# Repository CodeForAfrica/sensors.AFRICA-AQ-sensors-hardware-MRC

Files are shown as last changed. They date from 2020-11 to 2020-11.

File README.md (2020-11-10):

# sensors.AFRICA MRC AQ Kits Hardware

## Tools used

* Autodesk Eagle

* Fusion360

## sensors.AFRICA Stack

1. Firmware - https://github.com/CodeForAfrica/sensors.AFRICA-AQ-sensors-software
2. API - https://github.com/CodeForAfricaLabs/sensors.AFRICA-AQ-api
3. Map - https://github.com/CodeForAfrica/sensors.AFRICA-AQ-map-v2

## Documentation

The Documentation is under development.

## License

GNU General Public License v3.0

sensors.AFRICA is a citizen-science focused project by Code for Africa that seeks to address data gaps by providing low cost sensors, which people can use to measure and monitor the quality of the air, water, and environment in their communities. This web app seeks to be the public portal through which most users would discover and explore the data and intiative.

Copyright (C) 2019 Code for Africa

This program is free software: you can redistribute it and/or modify
it under the terms of the GNU General Public License as published by
the Free Software Foundation, either version 3 of the License, or
(at your option) any later version.

This program is distributed in the hope that it will be useful,
but WITHOUT ANY WARRANTY; without even the implied warranty of
MERCHANTABILITY or FITNESS FOR A PARTICULAR PURPOSE. See the
GNU General Public License for more details.

You should have received a copy of the GNU General Public License
along with this program. If not, see <https://www.gnu.org/licenses/>

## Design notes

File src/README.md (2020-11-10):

# sensors.AFRICA / MRC AQ sensors hardware

This folder contains the Eagle design files for the sensors.AFRICA MRC boards.

### Folders

* **AQ_sensor** The Printed Circuit Board of the AQ kit

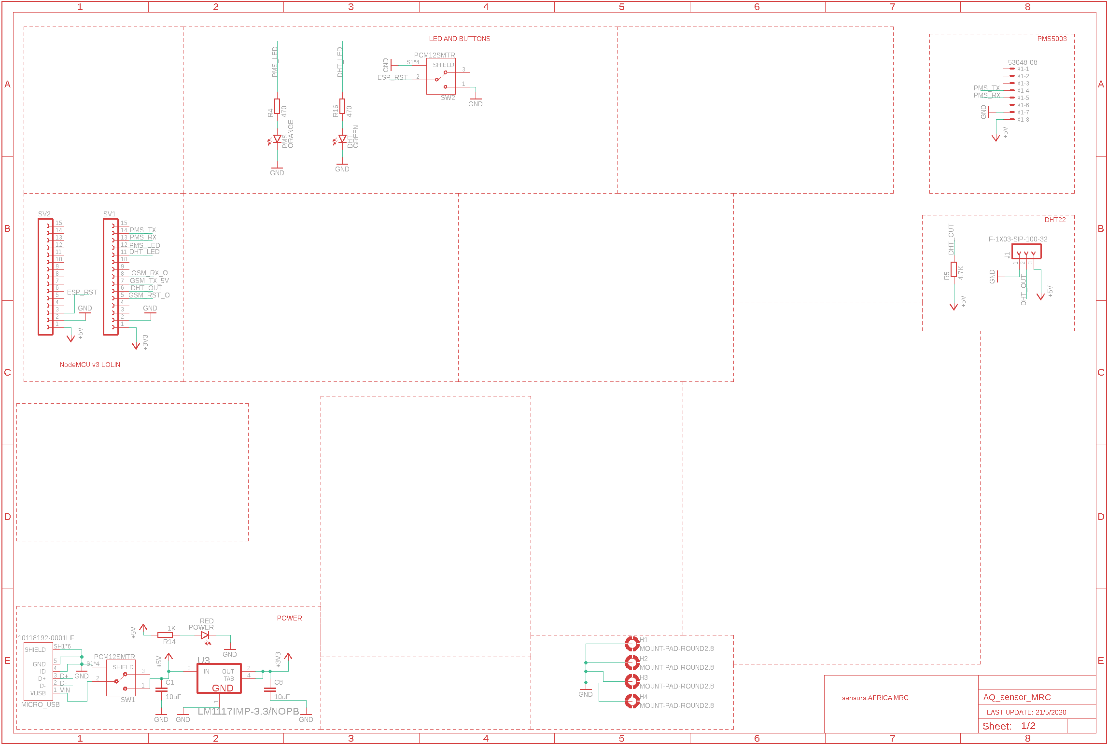
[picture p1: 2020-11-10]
src/AQ_sensor/AQ_sensor_MRC_schematic_sheet1.png

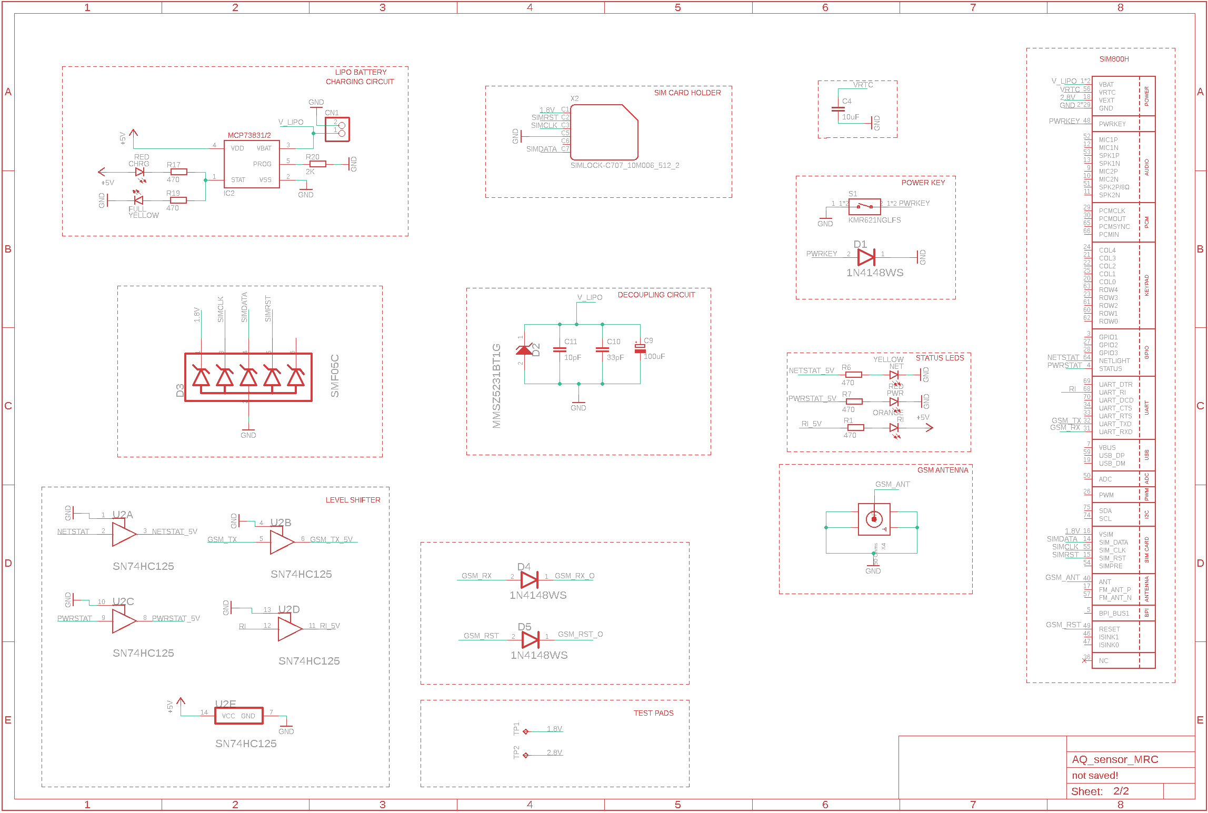
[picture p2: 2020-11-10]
src/AQ_sensor/AQ_sensor_MRC_schematic_sheet2.png

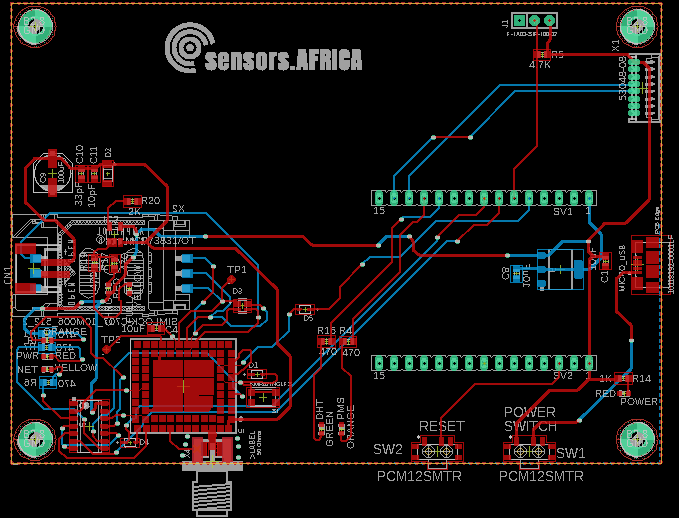
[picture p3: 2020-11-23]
src/AQ_sensor/AQ_sensor_MRC_brd.png

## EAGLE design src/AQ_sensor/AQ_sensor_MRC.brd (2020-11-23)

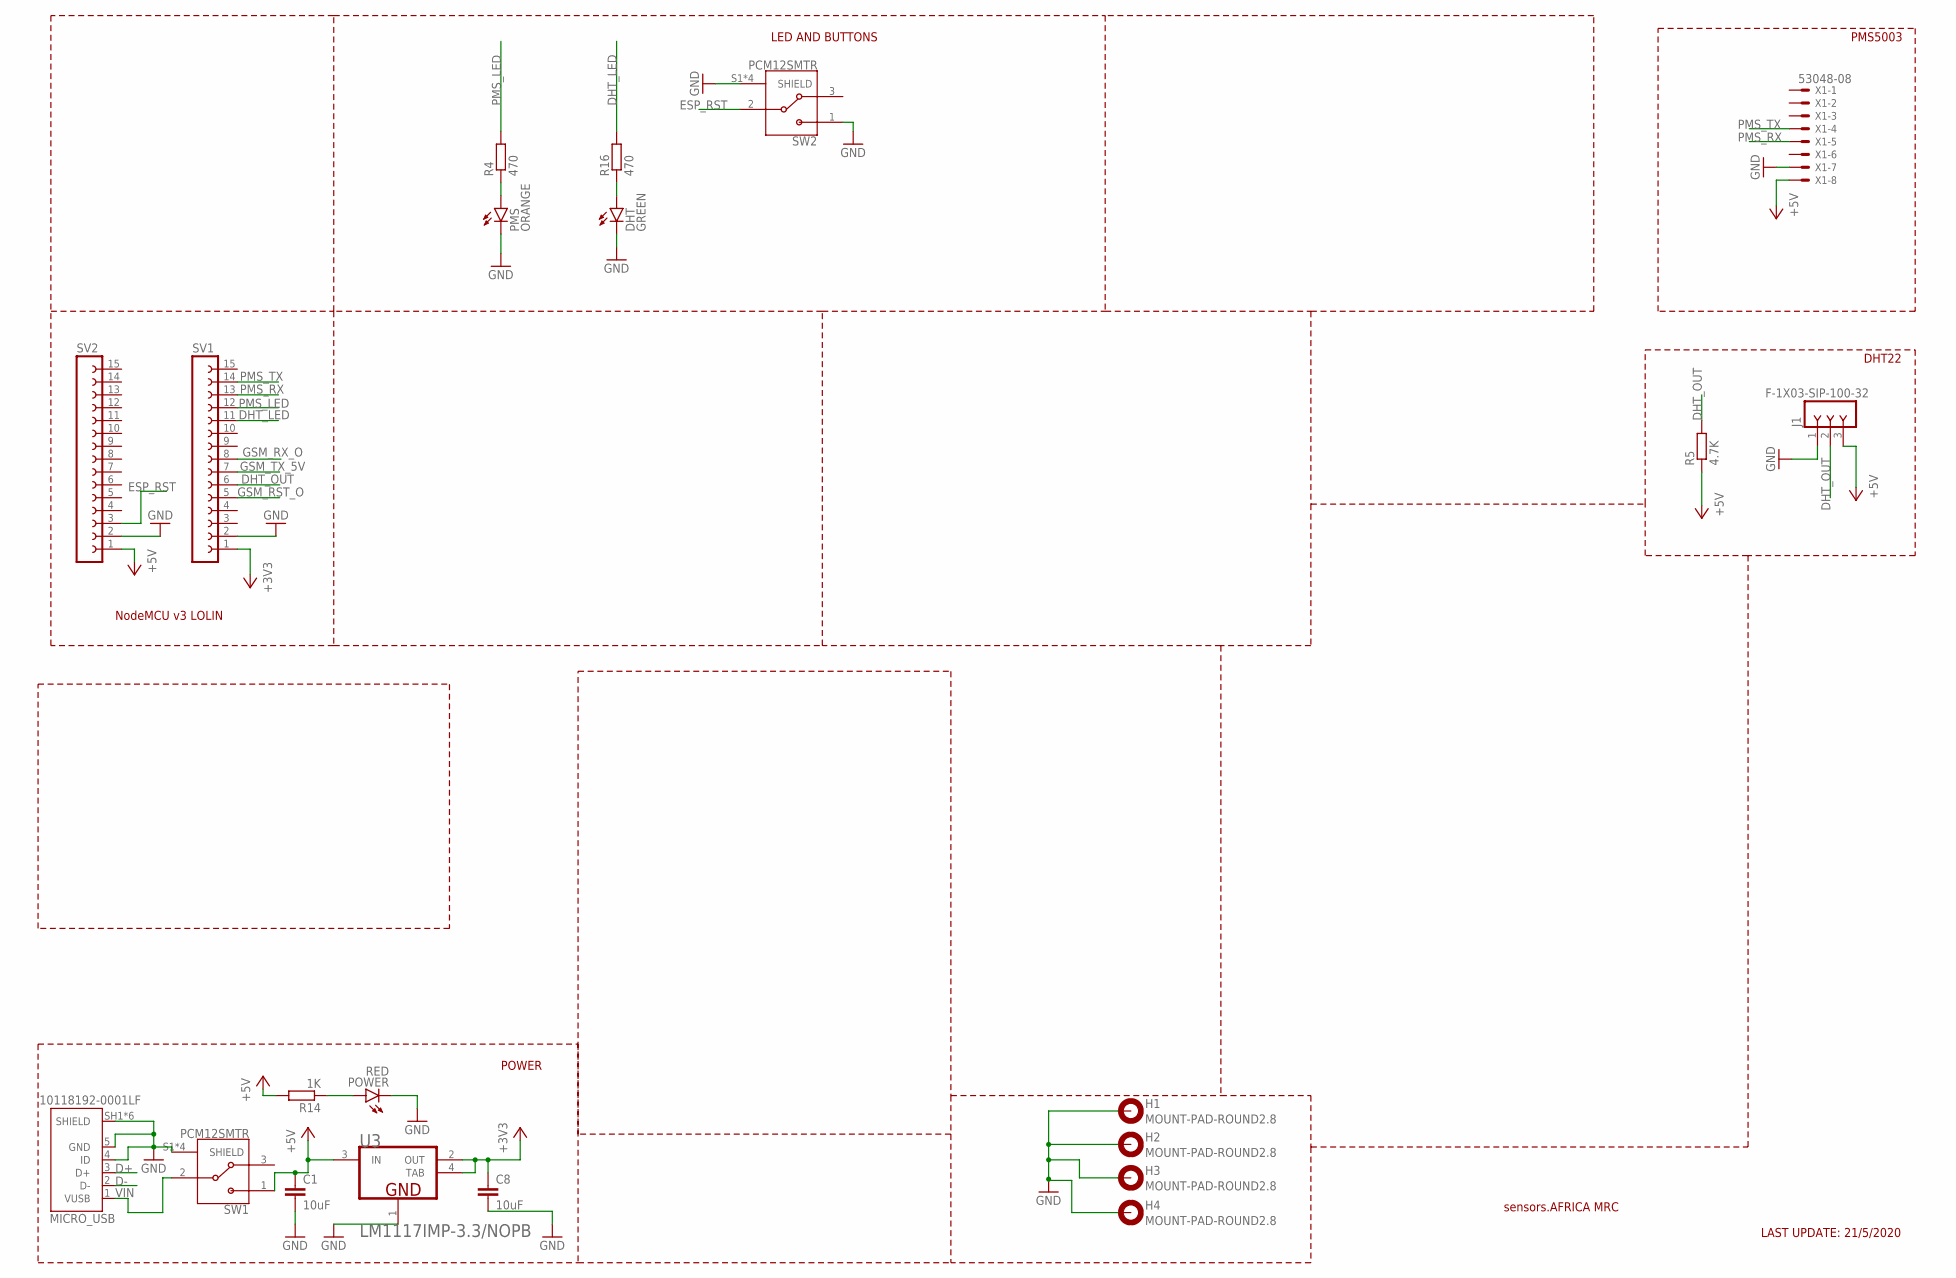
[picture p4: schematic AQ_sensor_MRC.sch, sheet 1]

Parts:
C1, C8: 10uF; C0603
DHT: GREEN; CHIP-LED0603
H1, H2, H3, H4: MOUNT-PAD-ROUND2.8; 2,8-PAD
J1: F-1X03-SIP-100-32; SIP-100-03-32
MICRO_USB: 10118192-0001LF; AMPHENOL_10118192-0001LF
PMS: ORANGE; CHIP-LED0603
POWER: RED; CHIP-LED0603
R4, R16: 470; R0603
R5: 4.7K; R0603
R14: 1K; R0603
SV1, SV2: FE15-1; FE15
SW1, SW2: PCM12SMTR; SW_PCM12SMTR
U3: TEXAS_INSTRUMENTS_LM1117IMP-3.3-NOPBTEXAS_INSTRUM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; TEXAS_INSTRUMENTS_LM1117IMP-3.3-NOPB_0
X1: 53048-08

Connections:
+3V3: C8.1, SV1.1, U3.2 (OUT), U3.4 (TAB)
+5V: C1.1, J1.3, R5.1, R14.2, SV2.1, SW1.1, U3.3 (IN), X1.8; also elsewhere on the board
D+: MICRO_USB.3 (D+)
D-: MICRO_USB.2 (D-)
DHT_LED: R16.2, SV1.11
DHT_OUT: J1.2, R5.2, SV1.6
ESP_RST: SV2.3, SW2.2
GND: C1.2, C8.2, DHT.C, H1.B2,8, H2.B2,8, H3.B2,8, H4.B2,8, J1.1, MICRO_USB.4 (ID), MICRO_USB.5 (GND), MICRO_USB.SH1 (SHIELD), MICRO_USB.SH2 (SHIELD), MICRO_USB.SH3 (SHIELD), MICRO_USB.SH4 (SHIELD), MICRO_USB.SH5 (SHIELD), MICRO_USB.SH6 (SHIELD), PMS.C, POWER.C, SV1.2, SV2.2, SW1.S1 (SHIELD), SW1.S2 (SHIELD), SW1.S3 (SHIELD), SW1.S4 (SHIELD), SW2.1, SW2.S1 (SHIELD), SW2.S2 (SHIELD), SW2.S3 (SHIELD), SW2.S4 (SHIELD), U3.1 (GND), X1.7; also elsewhere on the board
GSM_RST_O: SV1.5; also elsewhere on the board
GSM_RX_O: SV1.8; also elsewhere on the board
GSM_TX_5V: SV1.7; also elsewhere on the board
unnamed: PMS.A, R4.1
unnamed: POWER.A, R14.1
unnamed: DHT.A, R16.1
PMS_LED: R4.2, SV1.12
PMS_RX: SV1.13, X1.5
PMS_TX: SV1.14, X1.4
VIN: MICRO_USB.1 (VUSB), SW1.2

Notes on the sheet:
sensors.AFRICA MRC
LAST UPDATE: 21/5/2020
LED AND BUTTONS
PMS5003
DHT22
NodeMCU v3 LOLIN
POWER

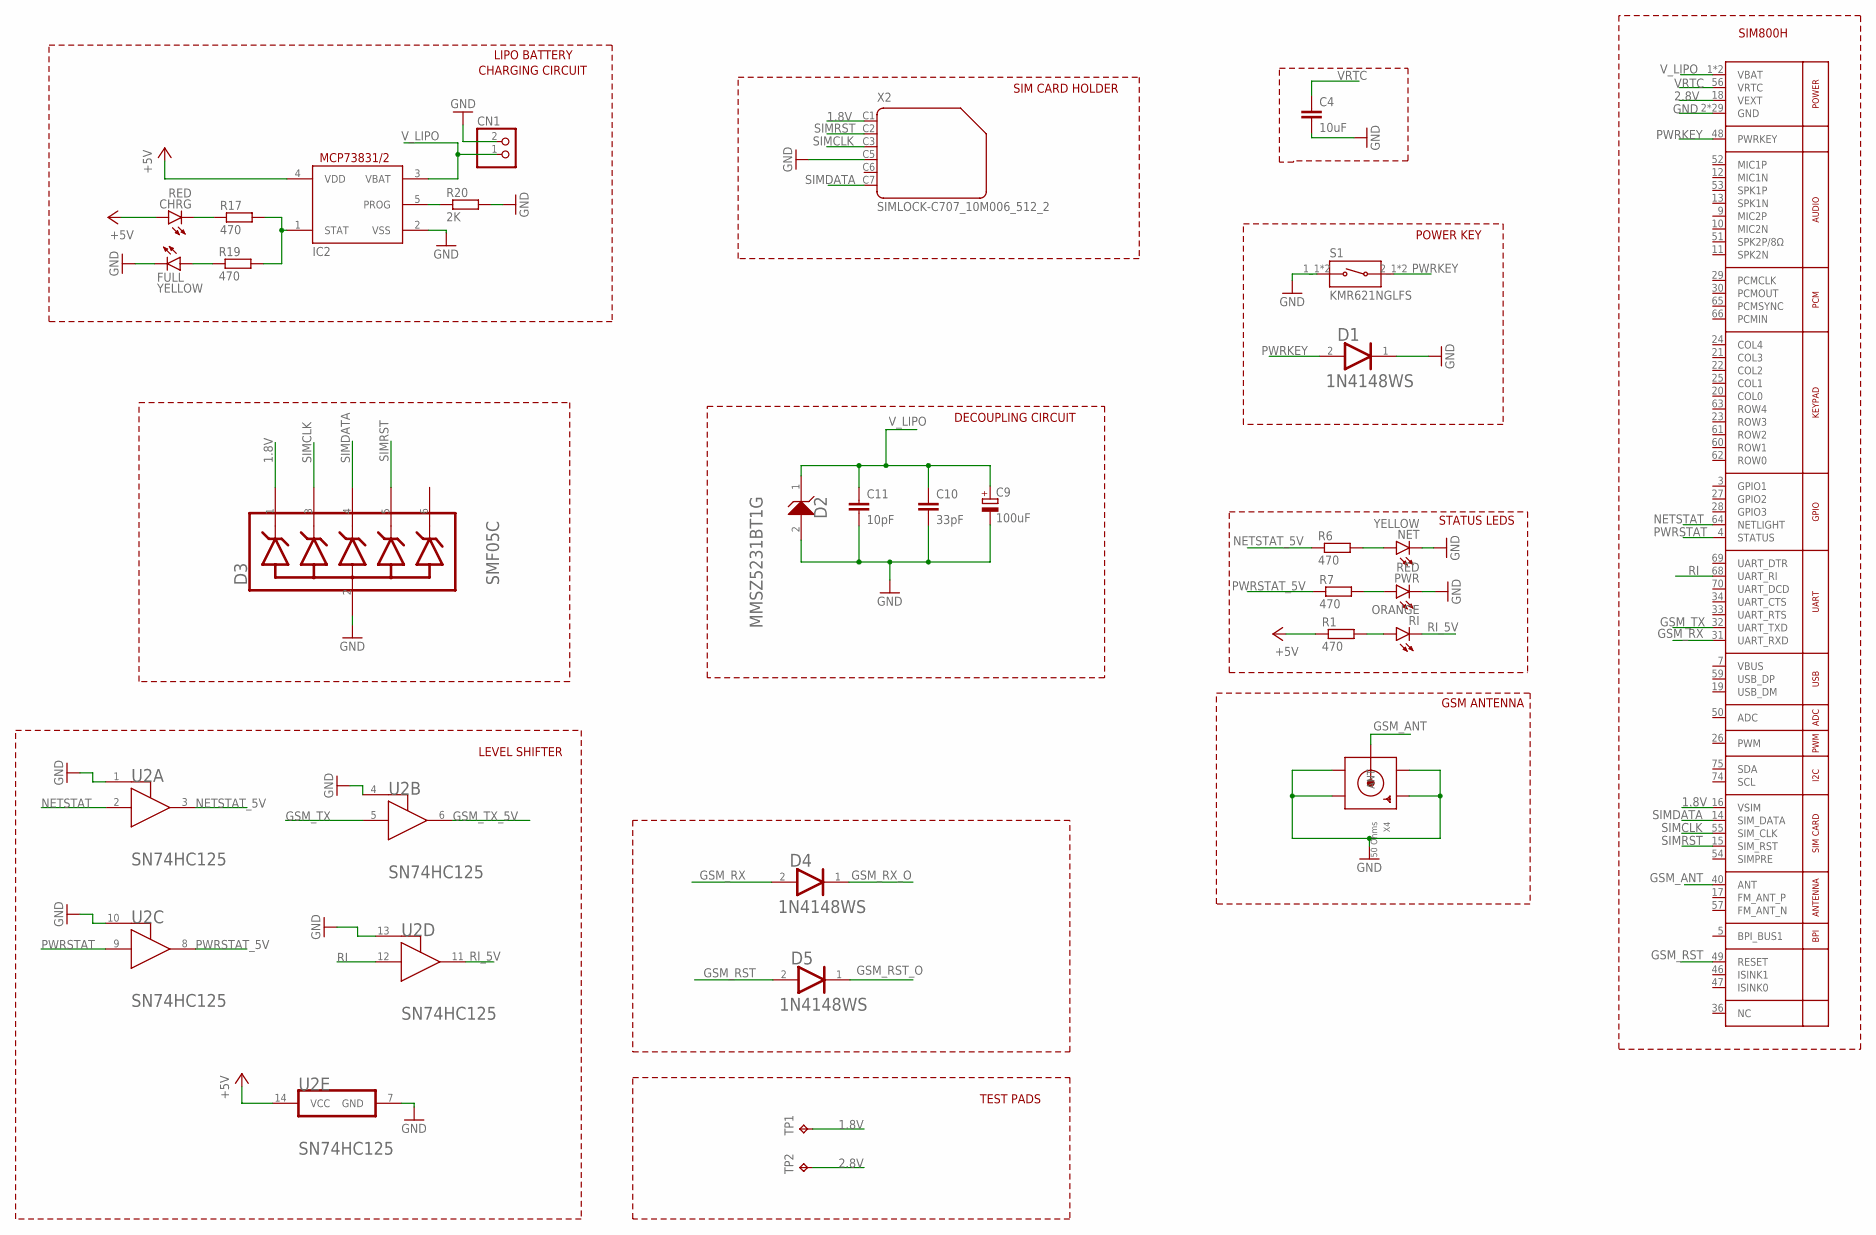
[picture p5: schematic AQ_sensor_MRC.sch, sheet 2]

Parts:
C4: 10uF; C0603
C9: 100uF; PANASONIC_D
C10: 33pF; C0603
C11: 10pF; C0603
CHRG: RED; CHIP-LED0603
CN1: JST_2PIN-SMT-RA; JST-PH-2-SMT-RA
D1, D4, D5: ON_SEMI_1N4148WSON_SEMI_1N4148WS_0_0; ON_SEMI_1N4148WS_0
D2: ON_SEMICONDUCTOR_MMSZ5231BT1GON_SEMICONDUCTOR_MMS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; ON_SEMICONDUCTOR_MMSZ5231BT1G_0
D3: SEMTECH_SMF05CSEMTECH_SMF05C_0_0; SEMTECH_SMF05C_0
FULL: YELLOW; CHIP-LED0603
IC2: MCP73831/OT; SOT23-5L
NET: YELLOW; CHIP-LED0603
PWR: RED; CHIP-LED0603
R1, R6, R7, R17, R19: 470; R0603
R20: 2K; R0603
RI: ORANGE; CHIP-LED0603
S1: KMR621NGLFS; SW_KMR621NGLFS
TP1, TP2: TPB1,27; B1,27
U1: GSM_SIM800L; SIM800L
U2: TEXAS_INSTRUMENTS_SN74HC125TEXAS_INSTRUMENTS_SN74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; TEXAS_INSTRUMENTS_SN74HC125_0
X2: SIMLOCK-C707_10M006_512_2; C707_10M006_512_2
X4: 50 Ohms; SMA_EDGELAUNCH_UFL

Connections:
1.8V: D3.1 (1_CATHODE), TP1.TP, U1.16 (VSIM), X2.C1 (1)
2.8V: TP2.TP, U1.18 (VEXT)
+5V: CHRG.A, IC2.4 (VDD), R1.1, U2.14 (VCC); also elsewhere on the board
GND: C4.2, C9.-, C10.2, C11.2, CN1.2 (1), D1.1 (CATHODE), D2.2 (A), D3.2 (ANODE), FULL.C, IC2.2 (VSS), NET.C, PWR.C, R20.2, S1.1_1 (1), S1.1_2 (1), U1.2 (GND), U1.6 (GND), U1.8 (GND), U1.35 (GND), U1.37 (GND), U1.38 (GND), U1.39 (GND), U1.41 (GND), U1.43 (GND), U1.44 (GND), U1.45 (GND), U1.58 (GND), U1.67 (GND), U1.71 (GND), U1.72 (GND), U1.73 (GND), U1.76 (GND), U1.77 (GND), U1.78 (GND), U1.79 (GND), U1.80 (GND), U1.81 (GND), U1.82 (GND), U1.83 (GND), U1.84 (GND), U1.85 (GND), U1.86 (GND), U1.87 (GND), U1.88 (GND), U2.1 (1_!OE!), U2.4 (4_!OE!), U2.7 (GND), U2.10 (2_!OE!), U2.13 (3_!OE!), X2.C5 (4), X4.GND@1 (GND1), X4.GND@2 (GND2), X4.GND@3 (GND3), X4.GND@4 (GND4); also elsewhere on the board
GSM_ANT: U1.40 (ANT), X4.P (ANT)
GSM_RST: D5.2 (ANODE), U1.49 (RESET)
GSM_RST_O: D5.1 (CATHODE); also elsewhere on the board
GSM_RX: D4.2 (ANODE), U1.31 (UART_RXD)
GSM_RX_O: D4.1 (CATHODE); also elsewhere on the board
GSM_TX: U1.32 (UART_TXD), U2.5 (2A)
GSM_TX_5V: U2.6 (2Y); also elsewhere on the board
unnamed: CHRG.C, R17.1
unnamed: IC2.1 (STAT), R17.2, R19.2
unnamed: NET.A, R6.2
unnamed: PWR.A, R7.2
unnamed: FULL.A, R19.1
unnamed: IC2.5 (PROG), R20.1
unnamed: R1.2, RI.A
NETSTAT: U1.64 (NETLIGHT), U2.2 (1A)
NETSTAT_5V: R6.1, U2.3 (1Y)
PWRKEY: D1.2 (ANODE), S1.2_1 (2), S1.2_2 (2), U1.48 (PWRKEY)
PWRSTAT: U1.4 (STATUS), U2.9 (3A)
PWRSTAT_5V: R7.1, U2.8 (3Y)
RI: U1.68 (UART_RI), U2.12 (4A)
RI_5V: RI.C, U2.11 (4Y)
SIMCLK: D3.3 (2_CATHODE), U1.55 (SIM_CLK), X2.C3 (3)
SIMDATA: D3.4 (3_CATHODE), U1.14 (SIM_DATA), X2.C7 (6)
SIMRST: D3.5 (4_CATHODE), U1.15 (SIM_RST), X2.C2 (2)
VBUS: U1.7 (VBUS)
VRTC: C4.1, U1.56 (VRTC)
V_LIPO: C9.+, C10.1, C11.1, CN1.1 (2), D2.1 (K), IC2.3 (VBAT), U1.1 (VBAT), U1.42 (VBAT)

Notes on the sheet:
SIM800H
POWER KEY
STATUS LEDS
SIM CARD HOLDER
CHARGING CIRCUIT
LIPO BATTERY
GSM ANTENNA
TEST PADS
LEVEL SHIFTER
DECOUPLING CIRCUIT

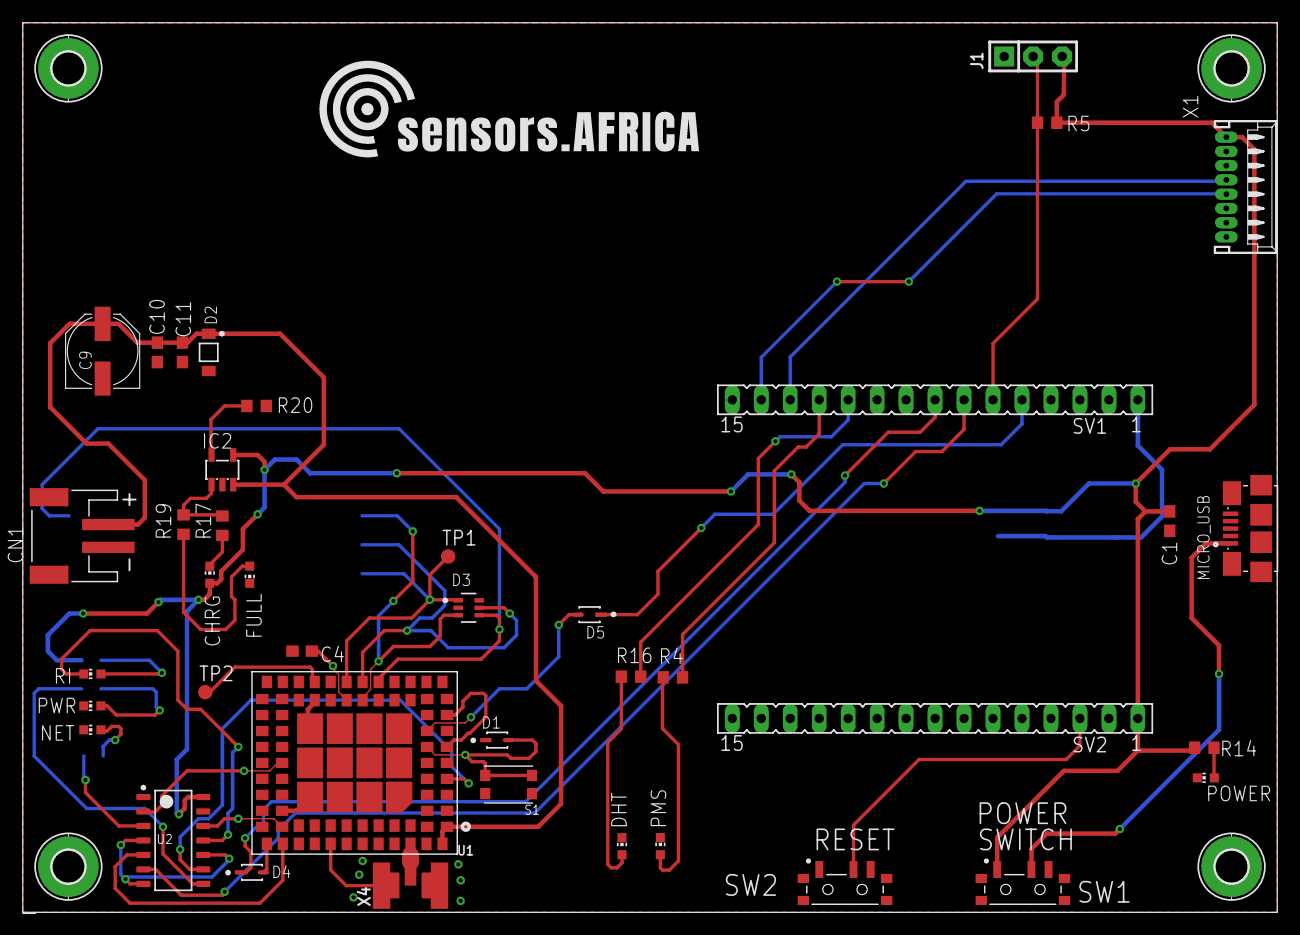
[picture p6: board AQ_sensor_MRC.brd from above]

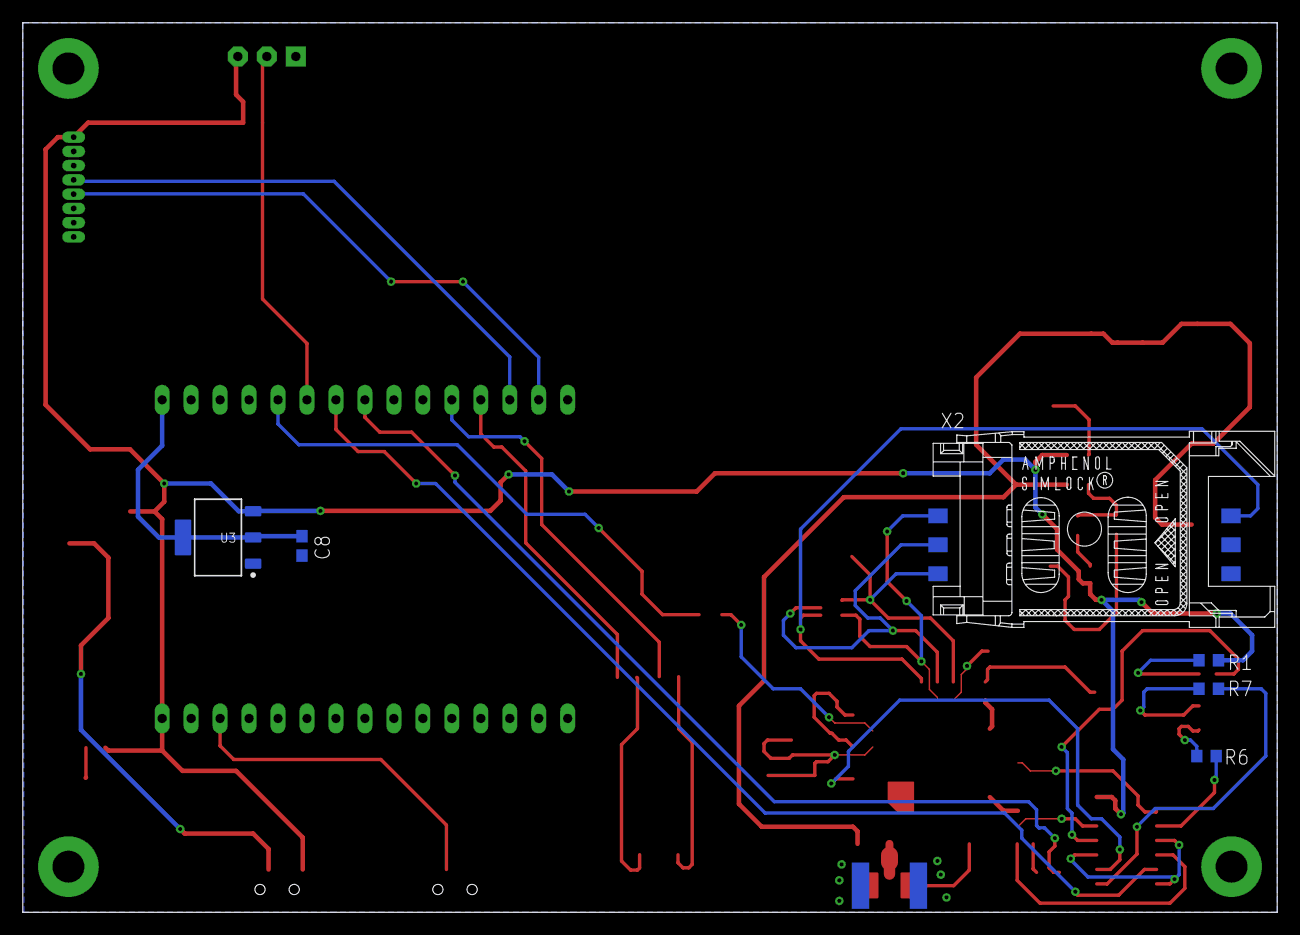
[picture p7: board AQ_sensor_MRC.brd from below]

Board: 2 copper layers, 110.0 x 78.0 mm, 50 parts (6 on the bottom side), 41 nets.

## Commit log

2020-11-10 MRC PCB design files
    [AQ_sensor_MRC.brd, AQ_sensor_MRC.sch]
2020-11-13 Added Managed library to design
    [AQ_sensor_MRC.brd, AQ_sensor_MRC.sch]
2020-11-16 Modifed RI LED connection
    [AQ_sensor_MRC.brd, AQ_sensor_MRC.sch]
2020-11-16 Added ground vias
    [AQ_sensor_MRC.brd]
